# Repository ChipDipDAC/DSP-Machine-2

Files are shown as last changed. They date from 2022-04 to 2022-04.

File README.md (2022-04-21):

# DSP-Machine-2
Hi-Res Streamer - Preamp, for Raspberry Pi, XLR analog out<br>
<a class="link" href="https://www.chipdip.ru/catalog-show/for-you-projects?p.0=ChipDipDac"><strong>DSP Machine 2</strong></a> - стример, цифроаналоговый преобразователь ЦАП, аудиопроцессор, для микрокомпьютеров Raspberry Pi.<br />
Для построения стримера вы можете использовать любой микрокомпьютер Raspberry Pi. Микрокомпьютер устанавливается на 40-пиновый разъем аудио карты. В качестве ПО используйте любой плеер или ОС образ, которых записан на микроSD карточку для Raspberry Pi. Операционные системы автоматически определяют аудиокарту ChipDip DAC и настраивают вывод звука именно на неё. В некоторых плеерах может понадобится выбрать в качестве устройства вывода звука - ChipDip DAC.<br />
<br />
- Plug and Play не требует пайки<br />
- Совместим с Raspberry Pi<br />
- Официальная поддержка RaspberryPi OS / Volumio3 / rAudio1 / Album Player / OpenELEC / Manjaro OS / MoOde и другими.<br />
- Высококачественный ЦАП PCM5242 для наилучшего качества звука.<br />
- Разъемы аудиовыхода: 2 x XLR (левый и правый)<br />
- Встроенная EEPROM для автоматической настройки ОС (с защитой от записи).<br />
- Автоматическое переключение частот в соответствии с входными сигналами I2S.<br />
- Диапазон частот дискретизации и разрядности от 44,1кГц/16 бит до 192кГц/32 бит<br />
- Совместим с ПО PurePathStudio и ChipStudio для перестройки аудиопроцессора<br />
Задать вопросы можно на форуме в разделе <a class="link" href="https://forum.chipdip.ru/index.php#chipdip-dac.39">ChipDip DAC</a>
<p><a class="galery" href="https://static.chipdip.ru/lib/992/DOC015992684.jpg">Pins DSP Machine2</a></p>

<p><a class="galery" href="https://static.chipdip.ru/lib/992/DOC015992685.jpg">Pins DSP Machine2</a></p>

<h2>Что под крышкой *</h2>

<p><a class="galery" href="https://static.chipdip.ru/lib/027/DOC016027920.jpg">Pins DSP Machine2</a></p>

<p><a class="galery" href="https://static.chipdip.ru/lib/027/DOC016027929.jpg">Pins DSP Machine2</a></p>
* Микрокомпьютер Raspberry Pi в комплект не входит.

<h2>Сравнительная таблица</h2>

<table class="user_t">
	<tbody>
		<tr>
			<td class="tcenter">&nbsp;</td>
			<td class="tcenter">DSP Machine 1</td>
			<td class="tcenter">DSP Machine 2</td>
			<td class="tcenter">DSP Machine 3</td>
		</tr>
		<tr>
			<td class="tcenter">Темброблок</td>
			<td class="tcenter">+</td>
			<td class="tcenter">+</td>
			<td class="tcenter">+</td>
		</tr>
		<tr>
			<td class="tcenter">SuperBass</td>
			<td class="tcenter">+</td>
			<td class="tcenter">+</td>
			<td class="tcenter">+</td>
		</tr>
		<tr>
			<td class="tcenter">Mute</td>
			<td class="tcenter">+</td>
			<td class="tcenter">+</td>
			<td class="tcenter">+</td>
		</tr>
		<tr>
			<td class="tcenter">Блок питания</td>
			<td class="tcenter">+</td>
			<td class="tcenter">+</td>
			<td class="tcenter">+</td>
		</tr>
		<tr>
			<td class="tcenter">Корректное выключение</td>
			<td class="tcenter">+</td>
			<td class="tcenter">+</td>
			<td class="tcenter">+</td>
		</tr>
		<tr>
			<td class="tcenter">Линейный выход</td>
			<td class="tcenter">-</td>
			<td class="tcenter">+</td>
			<td class="tcenter">+</td>
		</tr>
		<tr>
			<td class="tcenter">Усилитель мощности</td>
			<td class="tcenter">+</td>
			<td class="tcenter">-</td>
			<td class="tcenter">-</td>
		</tr>
		<tr>
			<td class="tcenter">Выход SPDIF</td>
			<td class="tcenter">-</td>
			<td class="tcenter">-</td>
			<td class="tcenter">+</td>
		</tr>
		<tr>
			<td class="tcenter">Выход Toslink</td>
			<td class="tcenter">-</td>
			<td class="tcenter">-</td>
			<td class="tcenter">+</td>
		</tr>
		<tr>
			<td class="tcenter">SigmaStudio</td>
			<td class="tcenter">+</td>
			<td class="tcenter">-</td>
			<td class="tcenter">+</td>
		</tr>
		<tr>
			<td class="tcenter">PurePathStudio</td>
			<td class="tcenter">-</td>
			<td class="tcenter">+</td>
			<td class="tcenter">-</td>
		</tr>
		<tr>
			<td class="tcenter">ChipStudio</td>
			<td class="tcenter">+</td>
			<td class="tcenter">+</td>
			<td class="tcenter">+</td>
		</tr>
	</tbody>
</table>
<br />

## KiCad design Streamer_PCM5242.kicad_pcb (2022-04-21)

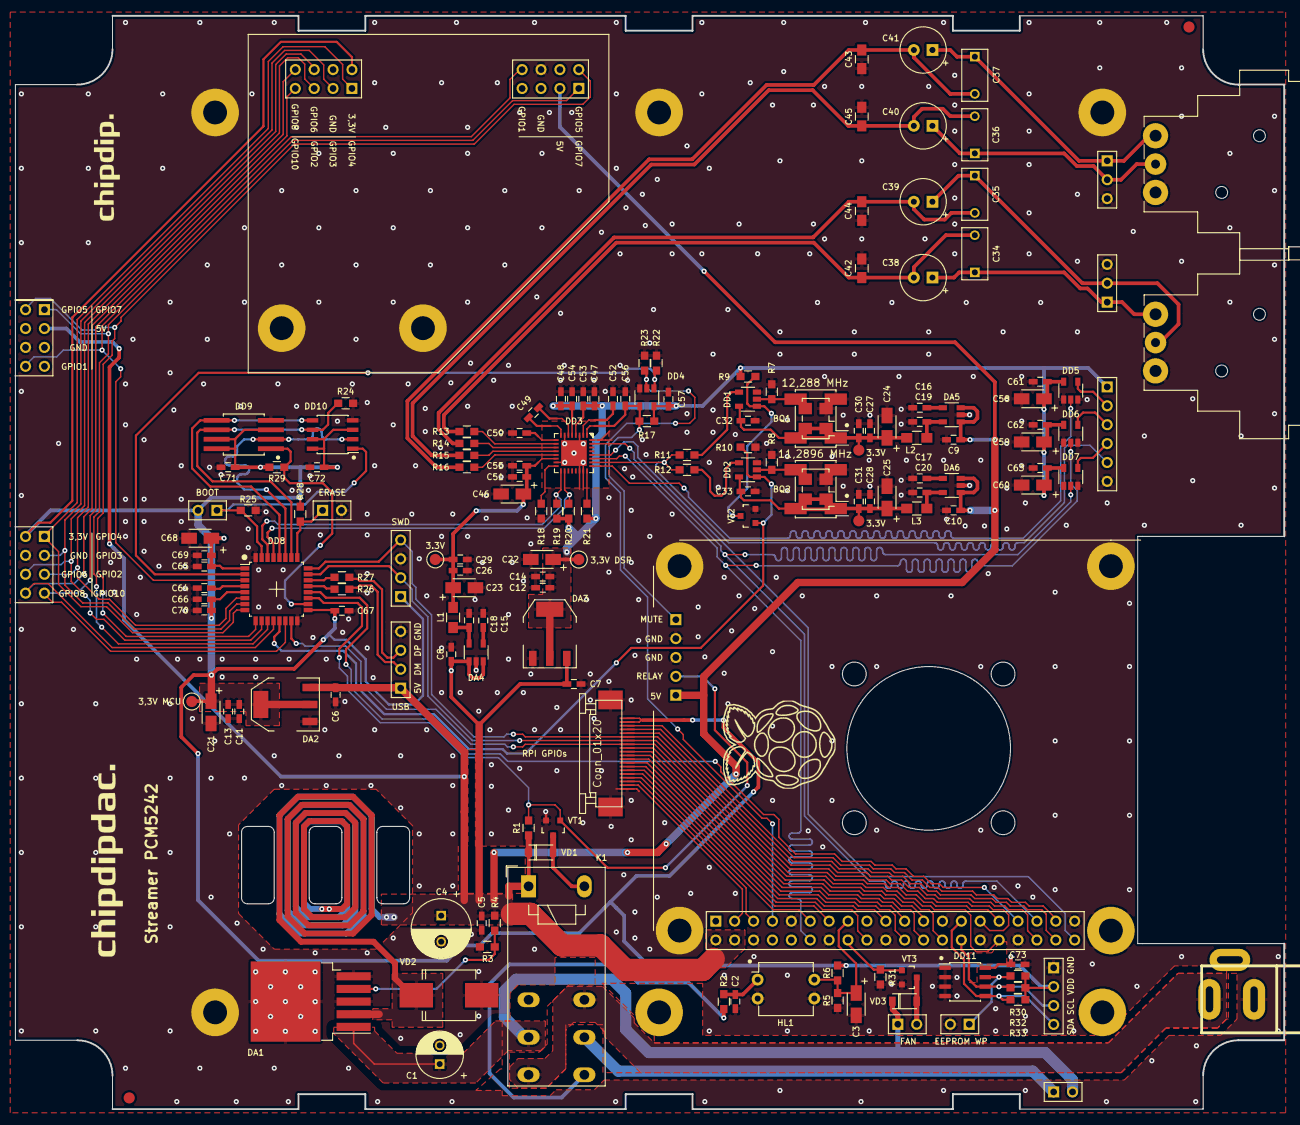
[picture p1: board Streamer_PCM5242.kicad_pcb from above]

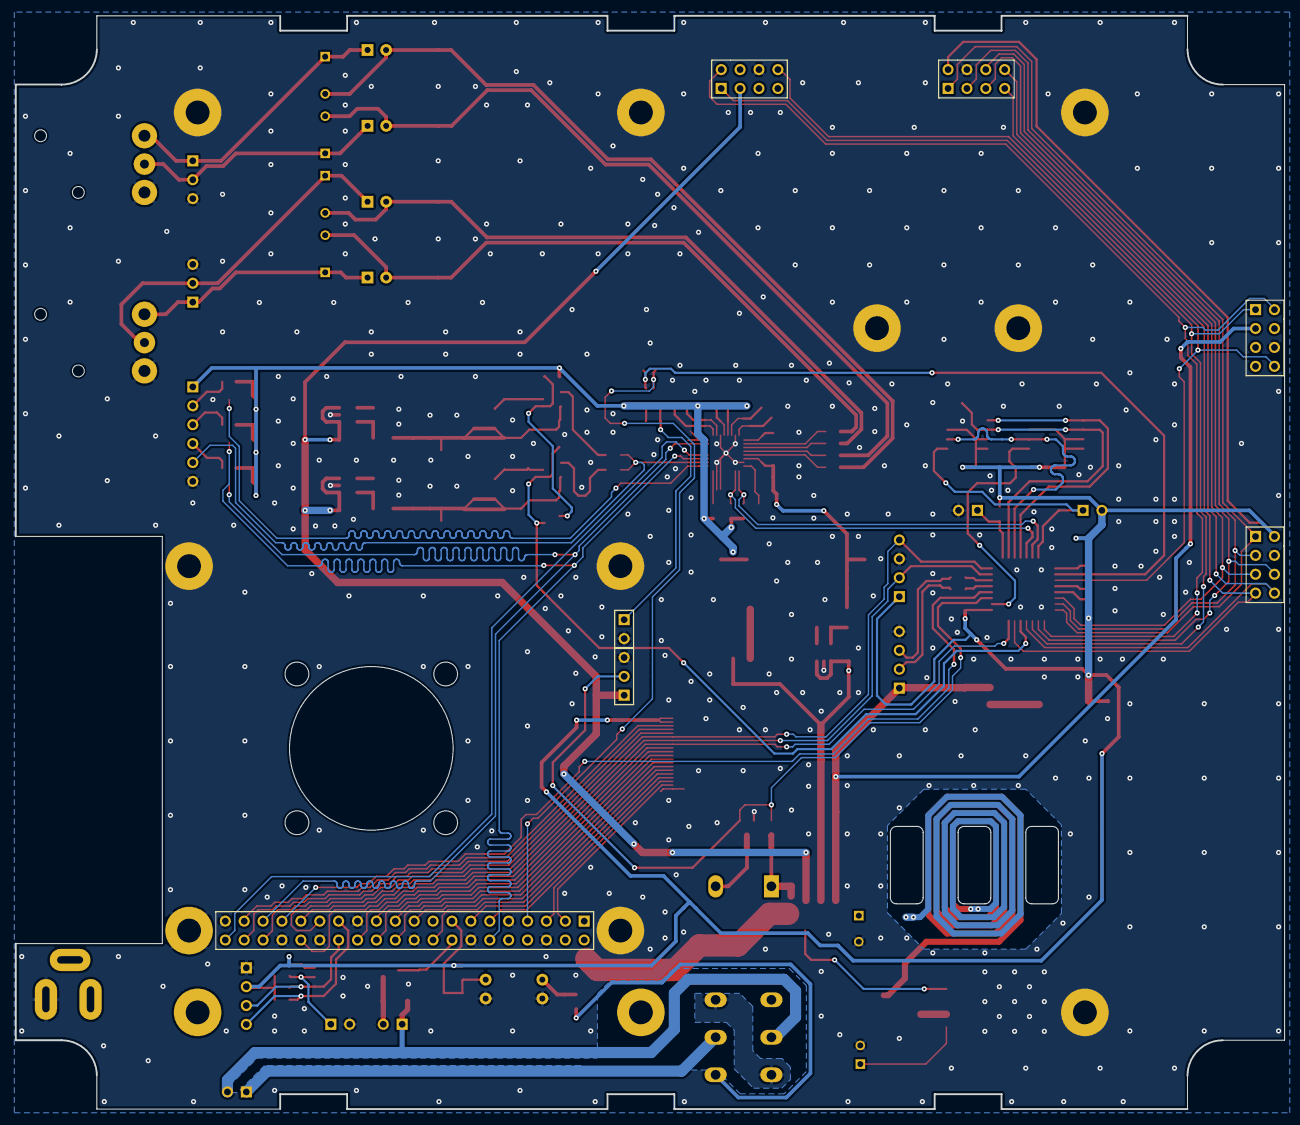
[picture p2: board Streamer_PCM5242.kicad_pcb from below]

Board: 2 copper layers, 170.6 x 147.0 mm, 165 parts (7 on the bottom side), 102 nets.

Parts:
BQ1: 12,288MHz; Oscillator_SMD_Fordahl_DFAS2-4Pin_7.3x5.1mm_HandSoldering
BQ2: 11,2896MHz; Oscillator_SMD_Fordahl_DFAS2-4Pin_7.3x5.1mm_HandSoldering
BQ3: 12,288MHz; Oscillator_SMD_EuroQuartz_XO53-4Pin_5.0x3.2mm_HandSoldering
BQ4: 11,2896MHz; Oscillator_SMD_EuroQuartz_XO53-4Pin_5.0x3.2mm_HandSoldering
C1: 100u; C_Radial_D6.3_L11.2_P2.5
C2: 10u; C_0603_HandSoldering
C3, C21, C22, C23, C24, C25, C46, C58, C59, C60, C68: 4.7u; TantalC_SizeA_EIA-3216_mm
C4: 1000u; C_Radial_D8_L11.5_P3.5
C5, C6, C7, C8, C9, C10, C11, C12, C13, C14, C18, C19, C20, C26, C27, C28, C47, C48, C49, C50, C51, C69, C70: 2.2u; C_0603_HandSoldering
C15, C16, C17: 0.01u; C_0603_HandSoldering
C29, C30, C31, C32, C33, C52, C53, C54, C55, C56, C57, C61, C62, C63, C64, C65, C66, C67, C71, C72, C73: 0.1u; C_0603_HandSoldering
C34, C35, C36, C37: 0.47u; C_Rect_L7_W3.5_P5
C38, C39, C40, C41: 10u; CP_Radial_Tantal_D6.0mm_P2.50mm
C42, C43, C44, C45: 2200p; C_0805_HandSoldering
DA1: LM2596S-ADJ; TO-263-5_TabPin3
DA2, DA3: LM1117-3.3; SOT-223
DA4, DA5, DA6: LP2985-3.3; SOT-23-5_mm
DD1, DD2: 74LVC1G125; SOT-23-5_mm
DD3: PCM5242; QFN-32-1EP_5x5mm_P0.5mm_EP3.45x3.45mm
DD4: NC7S08M5X; SOT-23-5_mm
DD5, DD6, DD7: MC74VHC1GT125; SOT-23-5_mm
DD8: STM32F042K6Tx; LQFP-32_7x7mm_Pitch0.8mm
DD9: 25LCxxx; SOIC-8_combo_Pitch1.27mm
DD10: 25LCxxx; SOIC-8_3.9x4.9mm_Pitch1.27mm
DD11: 24LC64; SOIC-8_3.9x4.9mm_Pitch1.27mm
HL1: P814; DIP-4_W7.62mm
K1: RTE2xxxx; Relay_DPDT_Schrack-RT2-FormC_RM5mm
L1, L2, L3: L; R_0805_HandSoldering
P1, P2, P3, P4, P5: Conn_01x01; Measurement_Point_Round-SMD-Pad_Small
R1, R6, R7, R8, R9, R10, R17, R18, R21, R22, R23, R24, R25, R28, R29, R30, R31: 10k; R_0603
R2: 2k; R_0603
R3: 1k; R_0603
R4: 3k; R_0603
R5: 15k; R_0603
R11, R12: 51R; R_0603
R13, R14, R15, R16: 470R; R_0603
R19, R20, R32, R33: 4k7; R_0603
R26, R27: 22; R_0603
VD1, VD3: D; SOD-123
VD2: D_Schottky; DIODE_SMC_Handsoldering
VT1, VT2, VT3: BSS138; SOT-23_mm
XP1, XP4, XP6: Conn_01x03; Pin_Header_Straight_1x03_mm
XP2, XP7, XP9, XP11, XP13, XP14: Conn_01x02; Pin_Header_Straight_1x02_mm
XP3, XP5: XLR3; Jack_XLR_Neutrik_NC3MAAH-1_Horizontal
XP8: Conn_01x06; Pin_Header_Straight_1x06_mm
XP10, XP12, XP15: Conn_01x04; Pin_Header_Straight_1x04_mm
XS1: Conn_01x03; JACK_DC
XS2, XS3, XS4, XS5: Conn_02x04_Odd_Even; Pin_Header_Straight_2x04_mm
XS6: Conn_02x20_Odd_Even; Pin_Header_Straight_2x20_mm
XS7: Conn_01x20; CONN20

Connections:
5V: C4.1, C5.1, C6.1, C7.1, C8.1, C9.1, C10.1, DA1.2, DA2.3, DA3.3, DA4.1, DA4.3, DA5.1, DA5.3, DA6.1, DA6.3, K1.A1, R1.1, R4.1, VD1.1, VD2.1, XP1.1, XP10.1, XS3.3, XS5.3, XS6.2, XS6.4
12V: K1.14, K1.22, XS1.1
BCLK: DD3.27, DD6.2, XS6.12
BCLK_OUT: DD6.4, XP8.3
BOOT\SPI1_NSS3: DD8.31, DD10.1, R25.1, XP9.1
DATA: DD3.28, XS6.40
DATA_OUT: DD5.4, XP8.2
FAN: R31.1, VT3.1, XS6.16
GEN_SEL: DD2.1, DD8.13, R10.1, VT2.1
GND: BQ1.2, BQ2.2, BQ3.2, BQ4.2, C1.2, C2.2, C3.2, C4.2, C5.2, C6.2, C7.2, C8.2, C9.2, C10.2, C11.2, C12.2, C13.2, C14.2, C15.2, C16.2, C17.2, C18.2, C19.2, C20.2, C21.2, C22.2, C23.2, C24.2, C25.2, C26.2, C27.2, C28.2, C29.2, C30.2, C31.2, C32.2, C33.2, C42.1, C43.2, C44.1, C45.2, C46.2, C47.2, C48.2, C50.2, C51.2, C52.2, C53.2, C54.2, C55.2, C56.2, C57.2, C58.2, C59.2, C60.2, C61.2, C62.2, C63.2, C64.2, C65.2, C66.2, C67.2, C68.2, C69.2, C70.2, C71.2, C72.2, C73.2, DA1.3, DA1.5, DA2.1, DA3.1, DA4.2, DA5.2, DA6.2, DD1.3, DD2.3, DD3.3, DD3.7, DD3.15, DD3.22, DD3.23, DD3.32, DD3.33, DD4.3, DD5.1, DD5.3, DD6.1, DD6.3, DD7.1, DD7.3, DD8.16, DD8.32, DD9.4, DD10.4, DD11.1, DD11.2, DD11.3, DD11.4, HL1.2, HL1.3, R3.1, R5.2, R7.1, R8.1, R10.2, R18.2, R22.1, R23.1, R24.1, R25.2, R31.2, VD2.2, VT1.2, VT2.2, VT3.2, XP1.3, XP3.1, XP4.3, XP5.1, XP6.3, XP7.2, XP8.6, XP10.4, XP11.2, XP12.3, XP13.2, XP15.1, XS1.2, XS2.4, XS3.6, XS4.4, XS5.6, XS6.6, XS6.9, XS6.14, XS6.20, XS6.25, XS6.30, XS6.34, XS6.39, XS7.20
GPIO1: DD8.3, XS3.8, XS5.8
GPIO2_BAL: DD8.6, XS2.5, XS4.5
GPIO3_VOL: DD8.7, XS2.3, XS4.3
GPIO4_KEY_1: DD8.8, XS2.1, XS4.1
GPIO5_KEY_2: DD8.9, XS3.2, XS5.2
GPIO6: DD3.25, DD5.2
GPIO6_TREBLE: DD8.10, XS2.6, XS4.6
GPIO7_BASS: DD8.11, XS3.1, XS5.1
GPIO8_LED_COMP: DD8.12, XS2.8, XS4.8
GPIO10_LED_MUTE: DD8.14, XS2.7, XS4.7
I2C1_SCL: DD3.18, DD8.29, R20.1
I2C1_SDA: DD3.17, DD8.30, R19.1
ID_SCL: DD11.6, R32.2, XP15.3, XS6.28
ID_SDA: DD11.5, R33.2, XP15.4, XS6.27
LR: DD3.31, DD7.2, XS6.35
LR_OUT: DD7.4, XP8.4
MUTE: DD4.2, R23.2, XS6.7
MUTE2: DD4.1, DD8.2, R22.2
MUTE_OUT: C56.1, DD3.1, DD4.4, R17.2, XP7.1
unnamed: BQ1.3, BQ3.3, DD1.2, R7.2
unnamed: BQ2.3, BQ4.3, DD2.2, R8.2
unnamed: C2.1, HL1.1, R2.2
unnamed: C15.1, DA4.4
unnamed: C16.1, DA5.4
unnamed: C17.1, DA6.4
unnamed: C18.1, DA4.5, L1.1
unnamed: C19.1, DA5.5, L2.1
unnamed: C20.1, DA6.5, L3.1
unnamed: C34.1, C38.1, XP3.2, XP4.1
unnamed: C34.2, C38.2, C42.2, R13.2
unnamed: C35.1, C39.1, XP3.3, XP4.2
unnamed: C35.2, C39.2, C44.2, R14.2
unnamed: C36.1, C40.1, XP5.3, XP6.2
unnamed: C36.2, C40.2, C45.1, R15.2
unnamed: C37.1, C41.1, XP5.2, XP6.1
unnamed: C37.2, C41.2, C43.1, R16.2
unnamed: C49.1, DD3.6
unnamed: C49.2, DD3.8
unnamed: C50.1, DD3.9
unnamed: C52.1, DD3.2
unnamed: DA1.4, R3.2, R4.2
unnamed: DD1.1, R9.2, VT2.3
unnamed: DD1.4, R11.2
unnamed: DD2.4, R12.2
unnamed: DD3.10, R13.1
unnamed: DD3.11, R14.1
unnamed: DD3.12, R15.1
unnamed: DD3.13, R16.1
unnamed: DD3.16, R18.1
unnamed: DD3.24, R21.2
unnamed: DD8.21, R26.1
unnamed: DD8.22, R27.1
unnamed: DD11.7, R30.2, XP13.1
unnamed: K1.21, XP2.1
unnamed: K1.24, R2.1
unnamed: K1.A2, VD1.2, VT1.3
unnamed: VD3.2, VT3.3, XP14.2
ON_OFF: C3.1, HL1.4, R5.1, R6.2, XS6.15
PWR_EVENT: DD8.20, XS6.33
RAS_GPIO2: XS6.3, XS7.19
RAS_GPIO3: XS6.5, XS7.18
RAS_GPIO7: XS6.26, XS7.9
RAS_GPIO8: XS6.24, XS7.11
RAS_GPIO9: XS6.21, XS7.12
RAS_GPIO10: XS6.19, XS7.14
RAS_GPIO11: XS6.23, XS7.10
RAS_GPIO16: XS6.36, XS7.5
RAS_GPIO17: XS6.11, XS7.17
RAS_GPIO20: XS6.38, XS7.4
RAS_GPIO25: XS6.22, XS7.13
RAS_GPIO26: XS6.37, XS7.3
RELAY: DD8.19, R1.2, VT1.1, XP1.2
RES0: XS6.18, XS7.15
RES1: XS6.13, XS7.16
RST: C64.1, DD8.4
SCK: DD3.26, R11.1, R12.1, XP8.5
SPI1_MISO: DD8.27, DD9.2, DD10.2
SPI1_MOSI: DD8.28, DD9.5, DD10.5
SPI1_NSS1: DD8.25, R28.2, XP11.1
SPI1_NSS2: DD8.18, DD9.1, R29.2
SPI1_SCK: DD8.26, DD9.6, DD10.6, R24.2
SR0: DD8.24, XP12.4, XS6.29, XS7.6
SR1: DD8.23, XP12.2, XS6.31, XS7.7
SR2: DD8.15, XS6.32, XS7.8
USB_DM: R26.2, XP10.2
USB_DP: R27.2, XP10.3
VDD: C11.1, C13.1, C21.1, C65.1, C66.1, C67.1, C68.1, C69.1, C70.1, C71.1, C72.1, C73.1, DA2.2, DA2.4, DD8.1, DD8.5, DD8.17, DD9.3, DD9.7, DD9.8, DD10.3, DD10.7, DD10.8, DD11.8, P1.1, R6.1, R28.1, R29.1, R30.1, R32.1, R33.1, XP9.2, XP12.1, XP15.2, XS2.2, XS4.2, XS7.1, XS7.2
VDDA: C23.1, C26.1, C29.1, C46.1, C51.1, C55.1, DD3.14, L1.2, P3.1
VDD_DSP: C12.1, C14.1, C22.1, C47.1, C48.1, C53.1, C54.1, C57.1, C58.1, C59.1, C60.1, C61.1, C62.1, C63.1, DA3.2, DA3.4, DD3.4, DD3.5, DD4.5, DD5.5, DD6.5, DD7.5, P2.1, R9.1, R17.1, R19.2, R20.2, R21.1, XP8.1
VDD_GEN1: BQ2.1, BQ2.4, BQ4.1, BQ4.4, C25.1, C28.1, C31.1, C33.1, DD2.5, L3.2, P5.1
VDD_GEN2: BQ1.1, BQ1.4, BQ3.1, BQ3.4, C24.1, C27.1, C30.1, C32.1, DD1.5, L2.2, P4.1
VIN: C1.1, DA1.1, K1.11, VD3.1, XP2.2, XP14.1

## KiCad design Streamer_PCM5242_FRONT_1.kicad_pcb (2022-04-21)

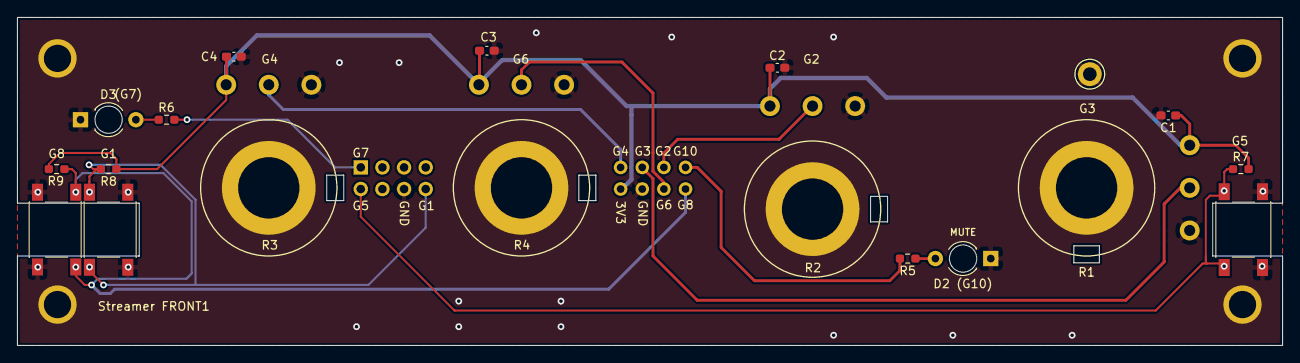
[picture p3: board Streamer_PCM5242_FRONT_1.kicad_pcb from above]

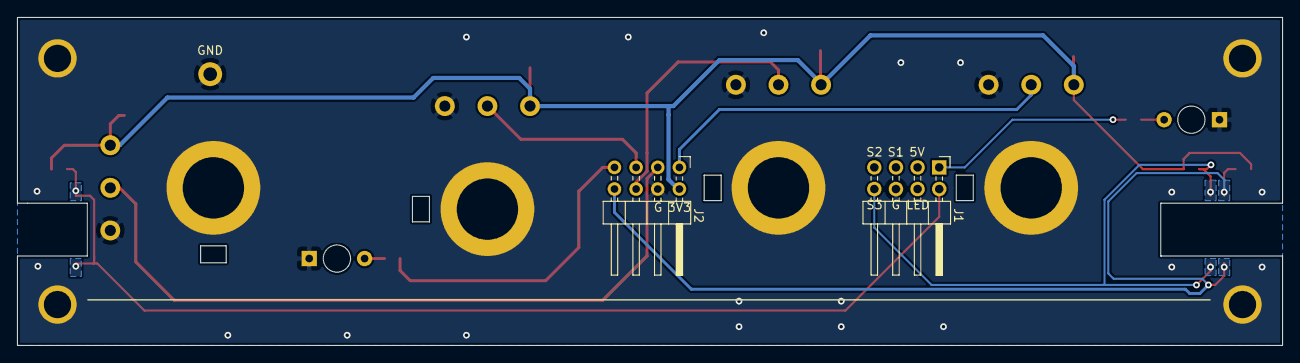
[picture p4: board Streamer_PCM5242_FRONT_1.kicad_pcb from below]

Board: 2 copper layers, 148.5 x 38.5 mm, 20 parts (2 on the bottom side), 13 nets.

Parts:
C1, C2, C3, C4: 0.1; C_0603_1608Metric_Pad1.08x0.95mm_HandSolder
D2 (G10), D3: LED; LED_D3.0mm
J1, J2: Conn_02x04_Odd_Even; PinHeader_2x04_P2.54mm_Horizontal
R1, R2, R3, R4: R_POT_TRIM; Potentiometer_Piher_PC-16_Single_Vertical
R5, R6: 560R; R_0603_1608Metric_Pad0.98x0.95mm_HandSolder
R7, R8, R9: 10k; R_0603_1608Metric_Pad0.98x0.95mm_HandSolder
SW1, SW2, SW3: SW_Push_Dual; SW_SPST_PTS645

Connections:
GND: C1.2, C2.2, C3.2, C4.2, D2 (G10).1, D3.1, J1.6, J2.4, R1.3, R2.3, R3.3, R4.3, SW1.1, SW2.1, SW3.1
GPIO1_COMP: J1.8, R8.2, SW2.2
GPIO2_BAL: J2.5, R2.2
GPIO3_VOL: J2.3, R1.2
GPIO4_BASS: J2.1, R3.2
GPIO5_MUTE: J1.2, R7.1, SW1.2
GPIO6_TREBLE: J2.6, R4.2
GPIO7\LED_COMP: J1.1, R6.2
GPIO8_SBASS: J2.8, R9.2, SW3.2
GPIO10\LED_MUTE: J2.7, R5.2
unnamed: D2 (G10).2, R5.1
unnamed: D3.2, R6.1
VDD: C1.1, C2.1, C3.1, C4.1, J2.2, R1.1, R2.1, R3.1, R4.1, R7.2, R8.1, R9.1
